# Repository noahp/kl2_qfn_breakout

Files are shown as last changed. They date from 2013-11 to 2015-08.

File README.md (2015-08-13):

kl2_qfn_breakout
================

Breakout for Freescale Kinetis MKL24Z64VFM4 in 32-QFN package.

http://www.freescale.com/webapp/sps/site/prod_summary.jsp?code=KL2  
front  
back

kl24 part
=====
mouser
-----
http://www.mouser.com/ProductDetail/Freescale-Semiconductor/MKL24Z64VFM4/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

digkey
-----
http://www.digikey.com/product-search/en?x=-1066&y=-70&lang=en&site=us&KeyWords=MKL24Z64VFM4

manual
-----
http://cache.freescale.com/files/32bit/doc/ref_manual/KL24P80M48SF0RM.pdf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

part spec
-----
http://www.mouser.com/ds/2/161/KL24P80M48SF0-218435.pdf

symbol
-----
http://www.freescale.com/files/capture/pdf/mkl24z32vfm4_qfn32.pdf

package
-----
http://www.freescale.com/webapp/search.partparamdetail.framework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

pads
-----
http://cache.freescale.com/files/shared/doc/package_info/98ASA00473D.pdf

other parts
=====
usb micro b
-----
[ebay micro b w/ mechanical](http://www.ebay.com/itm/50Pcs-Micro-USB-Type-B-Female-Socket-4-Vertical-Legs-fixed-Solder-Connectors-/171315639526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)  
[mouser micro b smt only](http://www.mouser.com/ProductDetail/FCI/10118192-0001LF/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)

10 pin header
-----
http://www.mouser.com/ProductDetail/FCI/20021121-00010T4LF/?qs=sGAEpiMZZMvffgRu4KC1R10eT3mhH9PKH6si4hSOVY4%3d

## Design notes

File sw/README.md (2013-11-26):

How to set up toolchain + debugger
=====
I'm using gcc-arm, codeblocks, and SEGGER J-Link.  
Note that I had good results with a project directory path with no spaces.

Setup
-----
1. download & install gcc-arm tools, I'm using v4.7-2013-q3-update.
2. download & install codeblocks, if on windows no need for mingw. I'm using v12.11 of codeblocks.
3. setup codeblocks debug settings under Settings->Debugger...
debug common settings  
CRITICAL! must check "Full (Debug) log for debug to work on my setup.  
add config  
Executable path is the path to arm-none-eabi-gdb  
config gcc arm debug
4. setup codeblocks with gcc-arm compiler & linker, Settings->Compiler...
compiler settings
compiler search dirs
under Advanced options...->Others
compiler advanced options
5. install SEGGER J-Link software. it's a good idea to check if you can connect to the target using the J-Link Commander tool, to verify your connections/drivers are working.

Use
-----
1. open the codeblocks project file.
2. start J-Link gdb server. I run the JLinkGDBServerCL with the following arguments:  
$JLinkGDBServer -select USB -device MKL25Z32xxx4 -if SWD -speed auto
3. start debugging. you should be able to set breakpoints etc. from within the IDE.

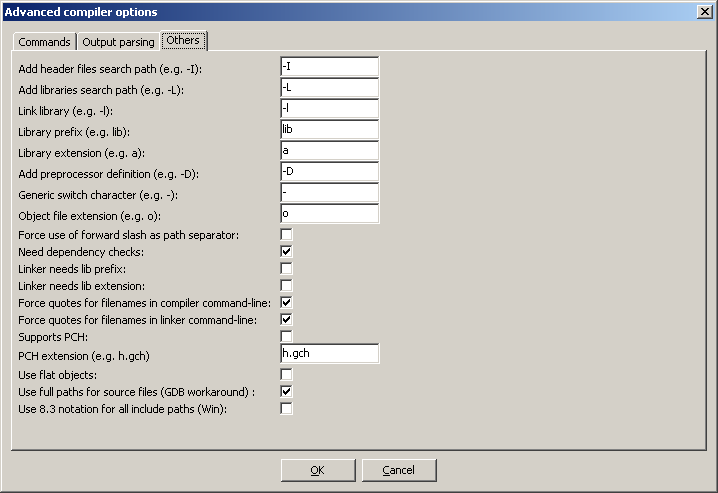
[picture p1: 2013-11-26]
sw/docs/compiler_adv.png

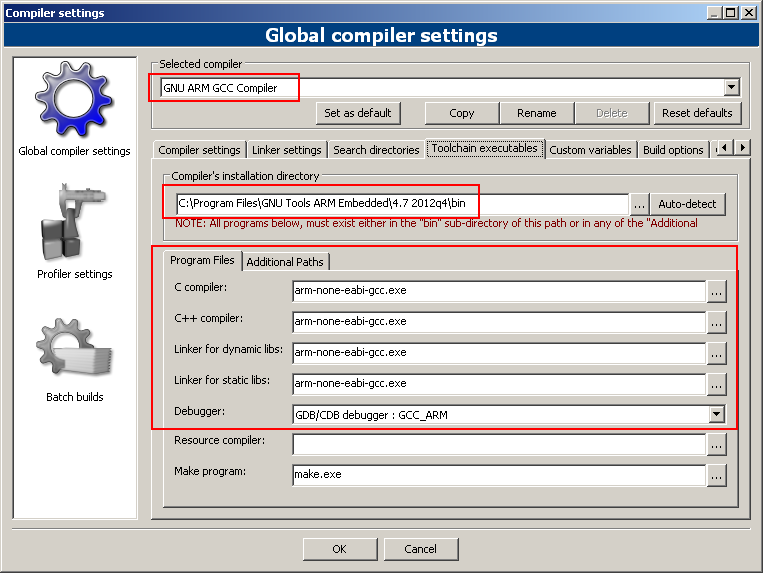
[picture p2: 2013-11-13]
sw/docs/compiler_cfg.png

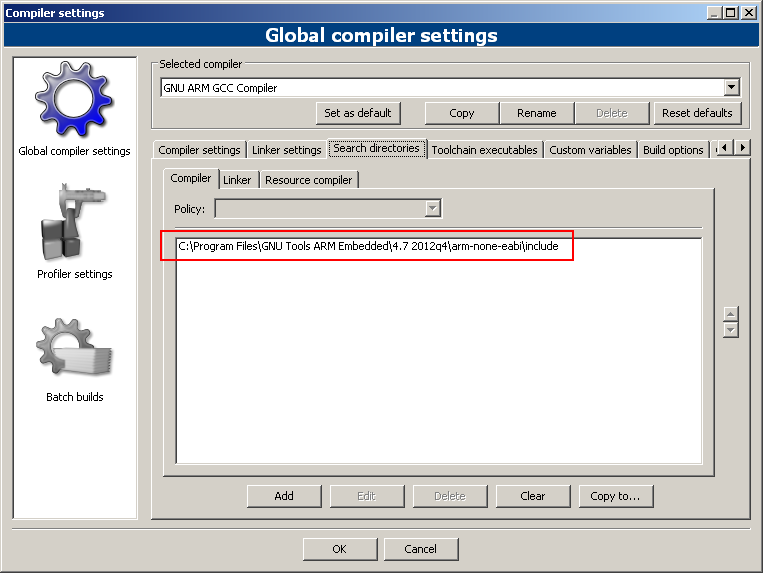
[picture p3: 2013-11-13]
sw/docs/compiler_cfg_search.png

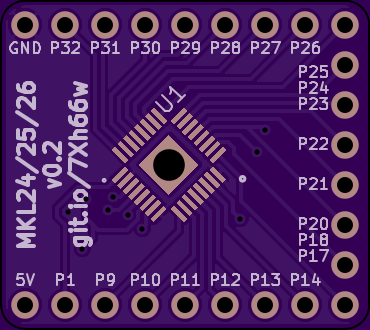
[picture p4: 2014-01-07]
hw/front_render.png

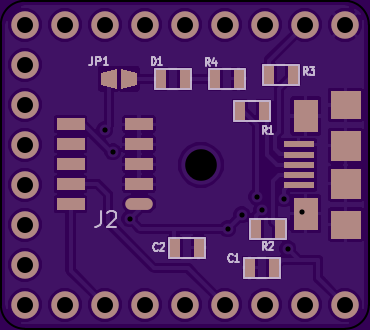
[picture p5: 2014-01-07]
hw/back_render.png

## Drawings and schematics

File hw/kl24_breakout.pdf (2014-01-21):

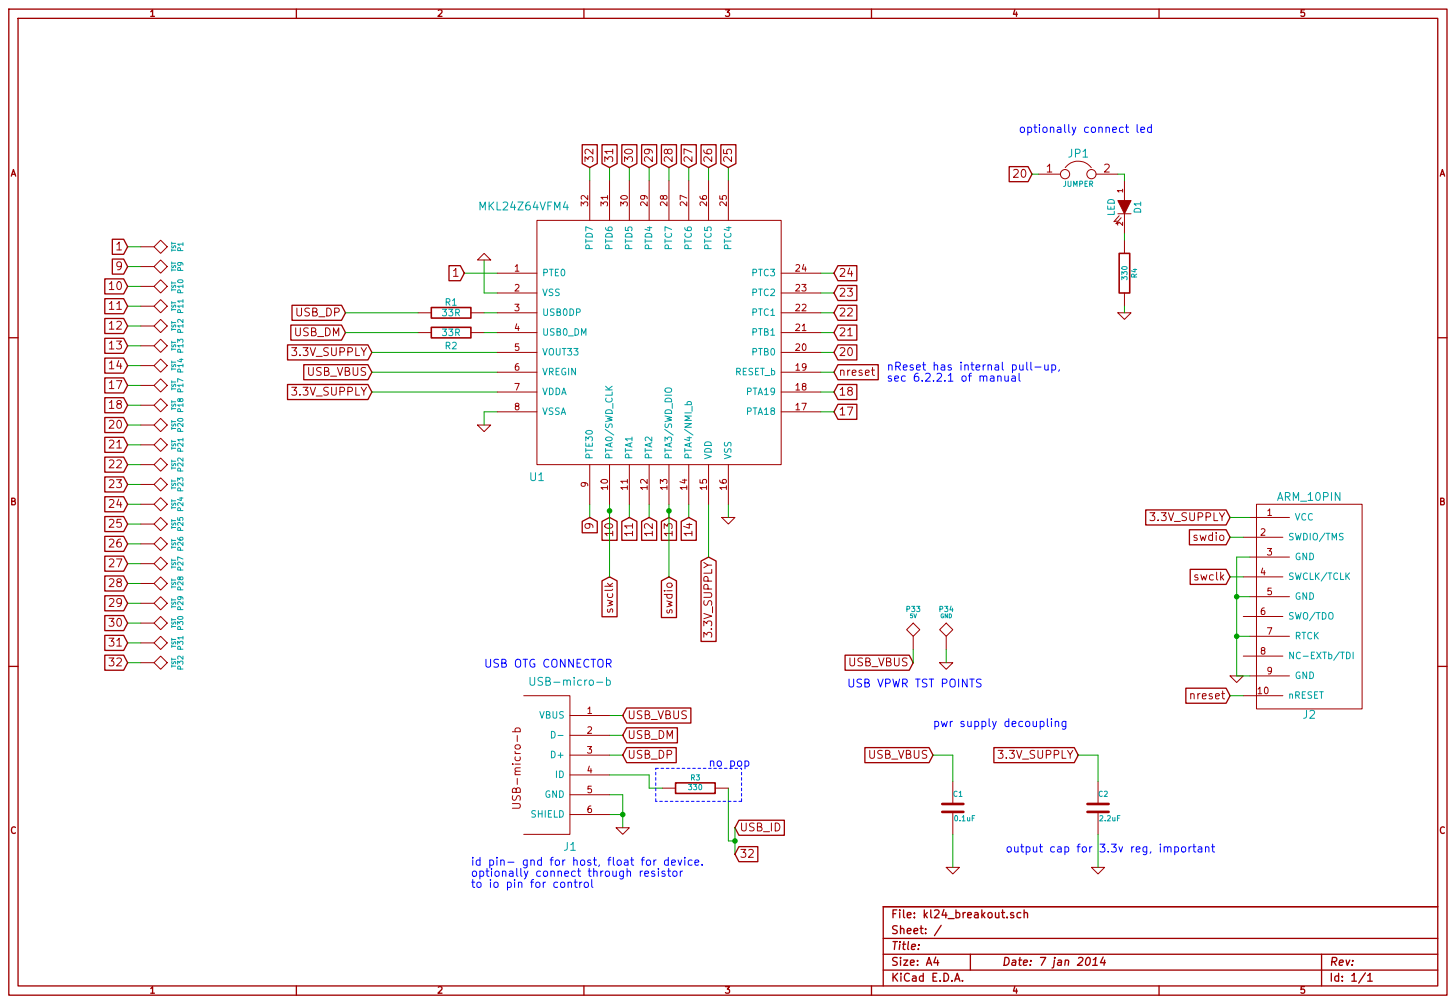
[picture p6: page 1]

optionally connect led
nReset has internal pull-up, sec 6.2.2.1 of manual pwr supply decoupling

USB VPWR TST POINTS

USB_ID
output cap for 3.3v reg, important 32

id pin- gnd for host, float for device.
optionally connect through resistor

Id: 1/1 Title: File: kl24_breakout.sch
Sheet: /

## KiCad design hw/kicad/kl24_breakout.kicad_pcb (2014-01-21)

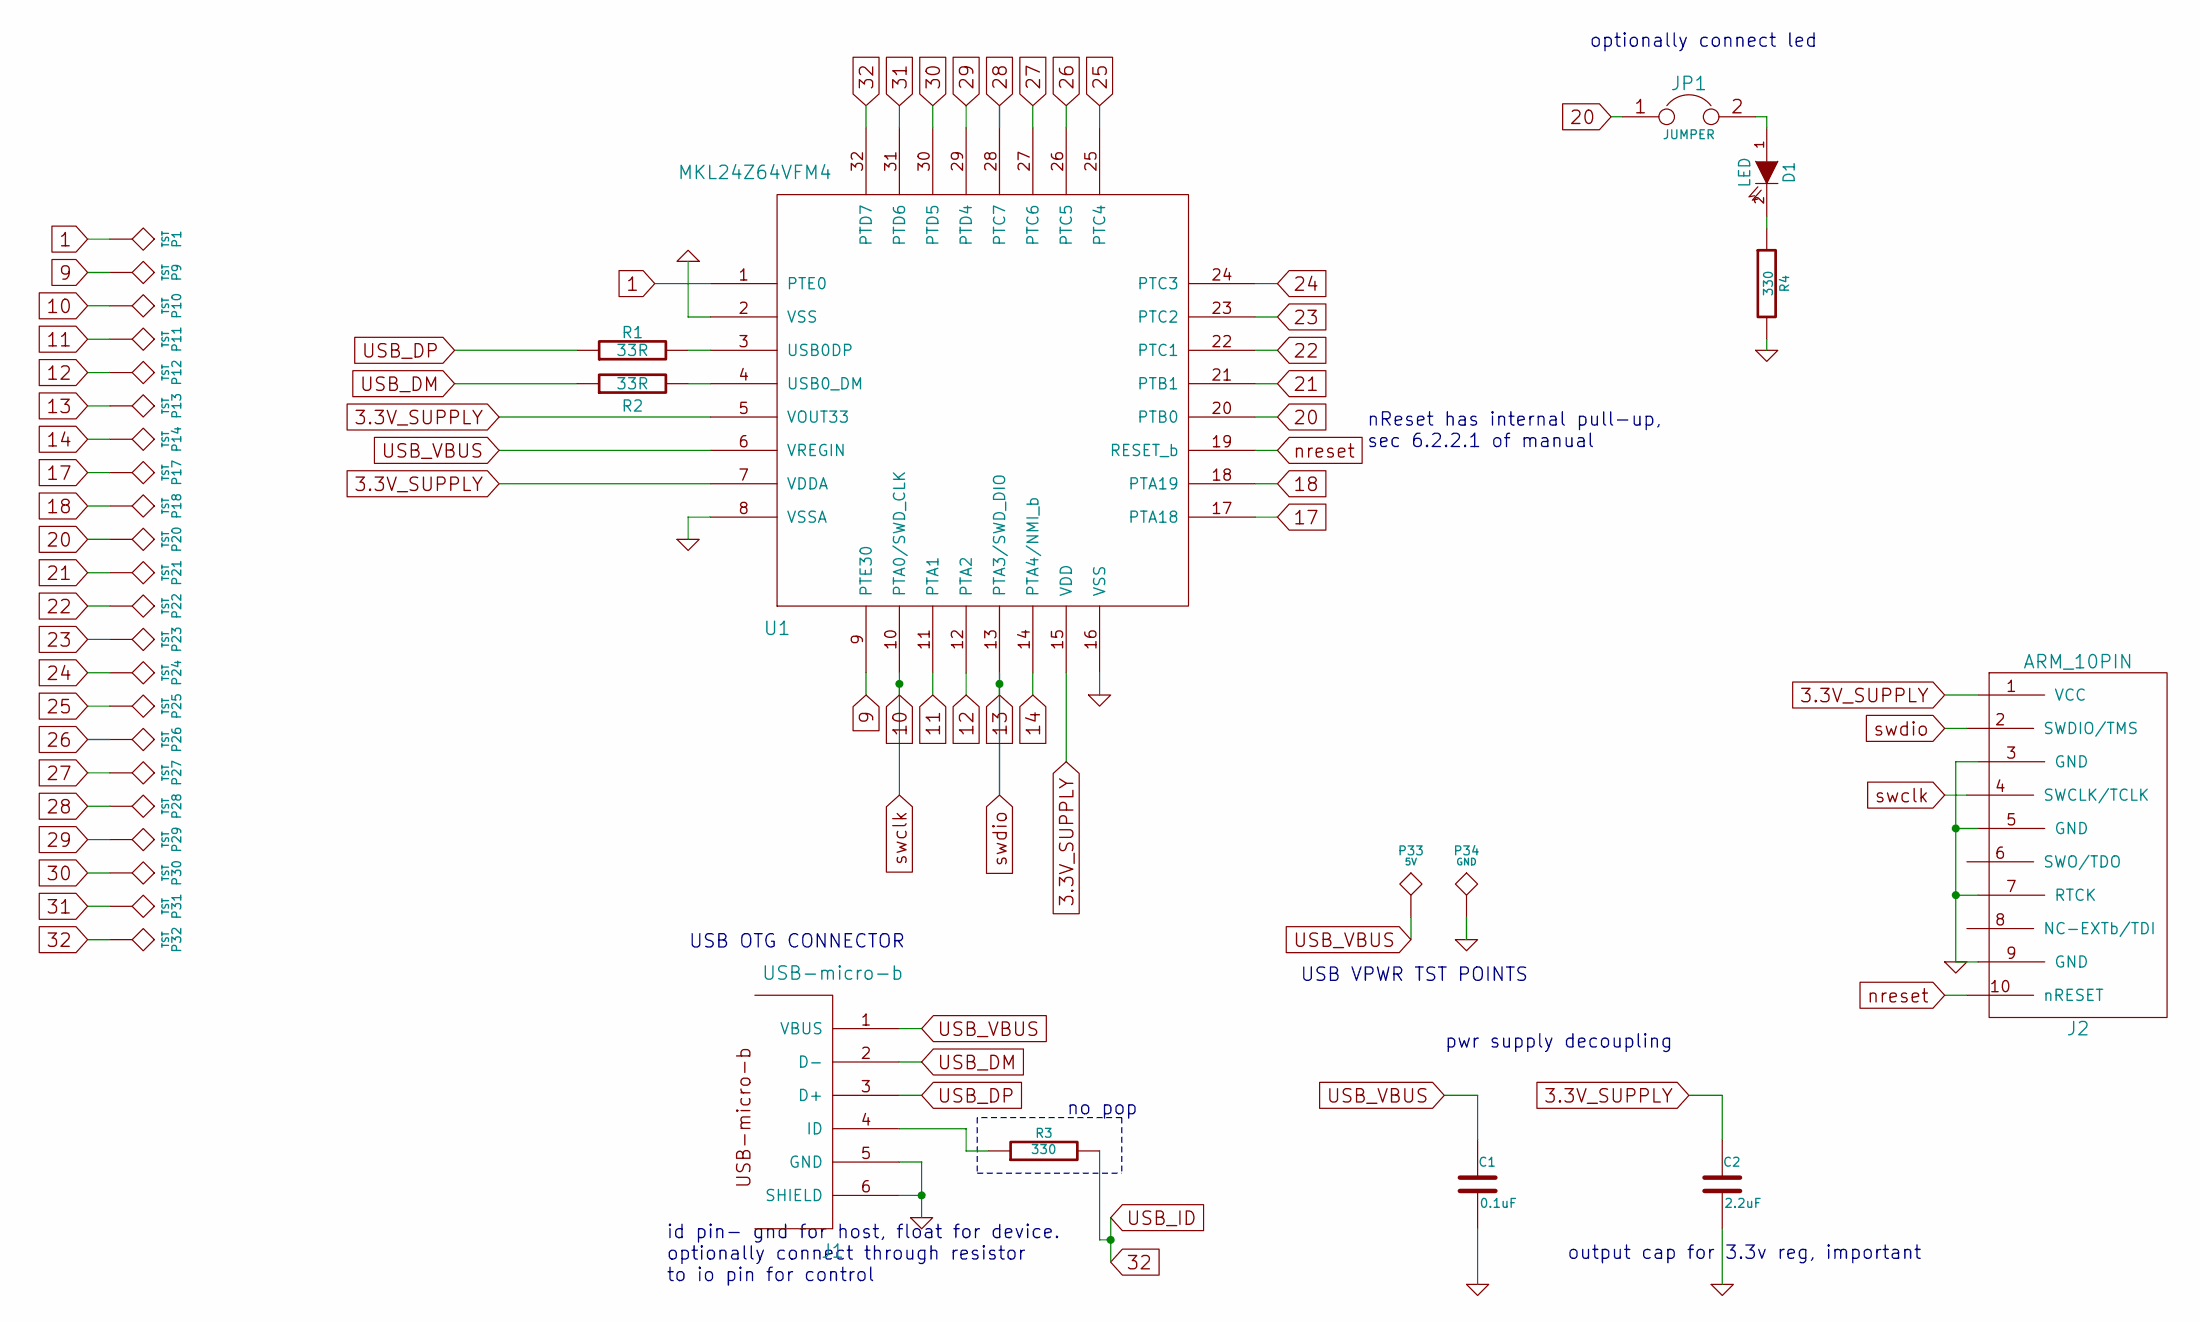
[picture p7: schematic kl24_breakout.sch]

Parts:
C1: 0.1uF
C2: 2.2uF
D1: LED
J1: USB-micro-b
J2: ARM_10PIN
JP1: JUMPER
P1, P9, P10, P11, P12, P13, P14, P17, P18, P20, P21, P22, P23, P24, P25, P26, P27, P28, P29, P30, P31, P32: TST
P33: 5V
P34: GND
R1, R2: 33R
R3, R4: 330
U1: MKL24Z64VFM4

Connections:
1: P1.1, U1.1 (PTE0)
3.3V_SUPPLY: C2.1, J2.1 (VCC), U1.5 (VOUT33), U1.7 (VDDA), U1.15 (VDD)
9: P9.1, U1.9 (PTE30)
10: J2.4 (SWCLK/TCLK), P10.1, U1.10 (PTA0/SWD_CLK)
11: P11.1, U1.11 (PTA1)
12: P12.1, U1.12 (PTA2)
13: J2.2 (SWDIO/TMS), P13.1, U1.13 (PTA3/SWD_DIO)
14: P14.1, U1.14 (PTA4/NMI_b)
17: P17.1, U1.17 (PTA18)
18: P18.1, U1.18 (PTA19)
20: JP1.1, P20.1, U1.20 (PTB0)
21: P21.1, U1.21 (PTB1)
22: P22.1, U1.22 (PTC1)
23: P23.1, U1.23 (PTC2)
24: P24.1, U1.24 (PTC3)
25: P25.1, U1.25 (PTC4)
26: P26.1, U1.26 (PTC5)
27: P27.1, U1.27 (PTC6)
28: P28.1, U1.28 (PTC7)
29: P29.1, U1.29 (PTD4)
30: P30.1, U1.30 (PTD5)
31: P31.1, U1.31 (PTD6)
32: P32.1, R3.2, U1.32 (PTD7)
GND: C1.2, C2.2, J1.5 (GND), J1.6 (SHIELD), J2.3 (GND), J2.5 (GND), J2.7 (RTCK), J2.9 (GND), P34.1, R4.2, U1.2 (VSS), U1.8 (VSSA), U1.16 (VSS)
unnamed: R1.2, U1.3 (USB0DP)
unnamed: R2.2, U1.4 (USB0_DM)
unnamed: J1.4 (ID), R3.1
unnamed: D1.1 (A), JP1.2
unnamed: D1.2 (K), R4.1
USB_DM: J1.2 (D-), R2.1
USB_DP: J1.3 (D+), R1.1
USB_VBUS: C1.1, J1.1 (VBUS), P33.1, U1.6 (VREGIN)
nreset: J2.10 (nRESET), U1.19 (RESET_b)

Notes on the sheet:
USB OTG CONNECTOR
id pin- gnd for host, float for device. optionally connect through resistor to io pin for control
USB VPWR TST POINTS
no pop
nReset has internal pull-up, sec 6.2.2.1 of manual
pwr supply decoupling
optionally connect led
output cap for 3.3v reg, important

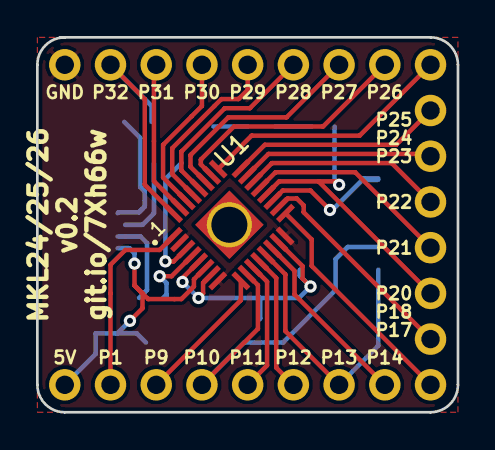
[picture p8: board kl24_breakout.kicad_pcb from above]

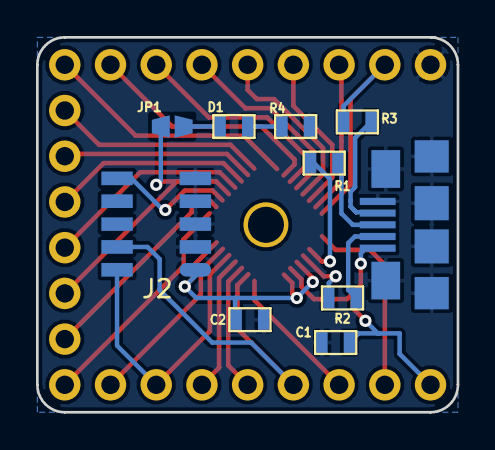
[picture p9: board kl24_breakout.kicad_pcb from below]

Board: 2 copper layers, 23.4 x 20.8 mm, 35 parts (10 on the bottom side), 33 nets.

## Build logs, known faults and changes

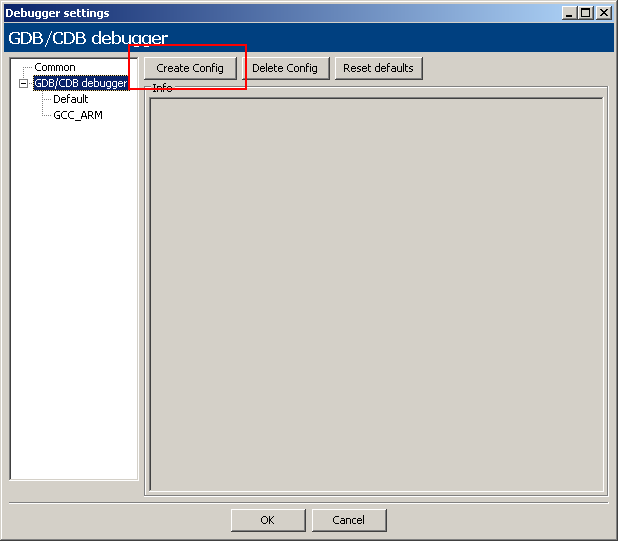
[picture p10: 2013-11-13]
sw/docs/gdb_debug.png

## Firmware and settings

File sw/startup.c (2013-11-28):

#include "MKL25Z4.h"

//*****************************************************************************
//
// Stack Configuration
//
//*****************************************************************************
//
// Stack size (in Words)
//
#define STACK_SIZE       0x00000100
__attribute__ ((section(".co_stack")))
unsigned long pulStack[STACK_SIZE];

//
// Flash configuration fields, be careful modifying these as the chip can be
//  permanently secured! See section 27.3.1 of the user manual,
//  "Flash Configuration Field Description".
//
__attribute__ ((section(".flashconfig")))
const unsigned long flashConfig[] = {
    0xffffffff, 0xffffffff,
    0xffffffff, 0xfffffffe,
};

#define WEAK __attribute__ ((weak))

//*****************************************************************************
//
// Declaration of the default fault handlers
//
//*****************************************************************************
void WEAK  ResetHandler(void);
void WEAK  NMIIntHandler(void);
void WEAK  HardFaultIntHandler(void);
void WEAK  MemManageIntHandler(void);
void WEAK  BusFaultIntHandler(void);
void WEAK  UsageFaultIntHandler(void);
void WEAK  SVCIntHandler(void);
void WEAK  DebugMonIntHandler(void);
void WEAK  PendSVIntHandler(void);
void WEAK  SysTickIntHandler(void);

void WEAK  DMA0IntHandler(void);
void WEAK  DMA1IntHandler(void);
void WEAK  DMA2IntHandler(void);
void WEAK  DMA3IntHandler(void);
void WEAK  FTFAIntHandler(void);
void WEAK  LVDIntHandler(void);
void WEAK  LLWUIntHandler(void);
void WEAK  I2C0IntHandler(void);
void WEAK  I2C1IntHandler(void);
void WEAK  SPI0IntHandler(void);
void WEAK  SPI1IntHandler(void);
void WEAK  UART0SEIntHandler(void);
void WEAK  UART1SEIntHandler(void);
void WEAK  UART2SEIntHandler(void);
void WEAK  ADCIntHandler(void);
void WEAK  ACMPIntHandler(void);
void WEAK  FTM0IntHandler(void);
void WEAK  FTM1IntHandler(void);
void WEAK  FTM2IntHandler(void);
void WEAK  RTCAIntHandler(void);
void WEAK  RTCSIntHandler(void);
void WEAK  PITIntHandler(void);
void WEAK  USBOTGIntHandler(void);
void WEAK  DACIntHandler(void);
void WEAK  TSIIntHandler(void);
void WEAK  MCGIntHandler(void);
void WEAK  LPTMRIntHandler(void);
void WEAK  PORTAIntHandler(void);
void WEAK  PORTDIntHandler(void);

// Start address for the initialization values of the .data section.
extern unsigned long _sidata;
// Start address for the .data section
extern unsigned long _sdata;
// End address for the .data section
extern unsigned long _edata;
// Start address for the .bss section
extern unsigned long _sbss;
// End address for the .bss section
extern unsigned long _ebss;
// End address for ram
extern void _eram;

extern int main(void);
void ResetHandler(void);
static void DefaultIntHandler(void);

//
// The minimal vector table for a Cortex M0+.  Note that the proper constructs
// must be placed on this to ensure that it ends up at physical address
// 0x00000000.
//
// page 53
__attribute__ ((section(".isr_vector")))
void (* const g_pfnVectors[])(void) =
{
    (void *)&pulStack[STACK_SIZE],          // The initial stack pointer
    ResetHandler,                           // The reset handler
    NMIIntHandler,                          // The NMI handler
    HardFaultIntHandler,                    // The hard fault handler
    0, 0, 0, 0, 0, 0, 0,                    // Reserved
    SVCIntHandler,                          // SVCall handler
    0, 0,                                   // Reserved
    PendSVIntHandler,                       // The PendSV handler
    SysTickIntHandler,                      // The SysTick handler

    DMA0IntHandler,                         // DMA channel 0 transfer complete
                                            // and error handler
    DMA1IntHandler,                         // DMA channel 1 transfer complete
                                            // and error handler
    DMA2IntHandler,                         // DMA channel 2 transfer complete
                                            // and error handler
    DMA3IntHandler,                         // DMA channel 3 transfer complete
                                            // and error handler
    0,                                      // Reserved
    FTFAIntHandler,                         // Command complete and read collision
    LVDIntHandler,                          // Low-voltage detect, low-voltage warning
    LLWUIntHandler,                         // Low Leakage Wakeup
    I2C0IntHandler,                         // I2C0 handler
    I2C1IntHandler,                         // I2C1 handler
    SPI0IntHandler,                         // SPI0 handler
    SPI1IntHandler,                         // SPI1 handler
    UART0SEIntHandler,                      // UART0SE handler
    UART1SEIntHandler,                      // UART1SE handler
    UART2SEIntHandler,                      // UART2SE handler
    ADCIntHandler,                          // ADC handler
    ACMPIntHandler,                         // ACMP handler
    FTM0IntHandler,                         // FTM0 handler
    FTM1IntHandler,                         // FTM1 handler
    FTM2IntHandler,                         // FTM2 handler
    RTCAIntHandler,                         // RTCA handler
    RTCSIntHandler,                         // RTCS handler
    PITIntHandler,                          // PIT handler
    0,                                      // Reserved
    USBOTGIntHandler,                       // USBOTG handler
    DACIntHandler,                          // DAC handler
    TSIIntHandler,                          // TSI handler
    MCGIntHandler,                          // MCG handler
    LPTMRIntHandler,                        // PIT handler
    0,                                      // Reserved
    PORTAIntHandler,                        // PORTA handler
    PORTDIntHandler,                        // PORTD handler
};

void StartupInitClock(void)
{
    // select Mid range of MCG_C4[DRST_DRS], and select DMX32=1.
    // from datasheet, in FEI MCG mode (which is what is used here),
    // setting C4[DMX32] is not recommended:
    //
    // "If the internal reference is trimmed to a frequency above 32.768 kHz,
    //  the greater FLL multiplication factor could potentially push the
    //  microcontroller system clock out of specification and damage the part."
    //
    // do it anyway to try to get closer to 48MHz. the mchck guys do it!
    // read-modify-write.
    MCG_C4 = (MCG_C4 & (~MCG_C4_DRST_DRS_MASK) & (~MCG_C4_DMX32_MASK)) |
              MCG_C4_DRST_DRS(0x1) | (0x1 << MCG_C4_DMX32_SHIFT);

    // debug, output bus clock on pin 24 (C3)
    // set CLKOUT select for "Bus clock", read-modify-write.
    SIM_SOPT2 = (SIM_SOPT2 & ~(SIM_SOPT2_CLKOUTSEL_MASK)) | SIM_SOPT2_CLKOUTSEL(0x2);
    // Enable PortC clock gate
    SIM_SCGC5 |= SIM_SCGC5_PORTC_MASK;
    // Set pin for CLKOUT
    PORTC_PCR3 = PORT_PCR_MUX(5) | PORT_PCR_DSE_MASK;
}

//*****************************************************************************
//
//! \brief This is the code that gets called when the processor first
//! starts execution following a reset event.
//!
//! \param None.
//!
//! Only the absolutely necessary set is performed, after which the
//! application supplied main() routine is called.
//!
//! \return None.
//
//*****************************************************************************
void Default_ResetHandler(void)
{
    unsigned long *pulSrc, *pulDest;

    // clock initialization first
    StartupInitClock();

    // Initialize data and bss
    // Copy the data segment initializers from flash to SRAM
    pulSrc = &_sidata;

    for(pulDest = &_sdata; pulDest < &_edata; )
    {
        *(pulDest++) = *(pulSrc++);
    }

    // Zero fill the bss segment.
    for(pulDest = &_sbss; pulDest < &_ebss; )
    {
        *(pulDest++) = 0;
    }

    // Call the application's entry point.
    main();

    // shouldn't return
    while(1);
}

//*****************************************************************************
//
// Provide weak aliases for each Exception handler to the DefaultIntHandler.
// As they are weak aliases, any function with the same name will override
// this definition.
//
//*****************************************************************************
#pragma weak ResetHandler = Default_ResetHandler
#pragma weak NMIIntHandler = DefaultIntHandler
#pragma weak HardFaultIntHandler = DefaultIntHandler
#pragma weak MemManageIntHandler = DefaultIntHandler
#pragma weak BusFaultIntHandler = DefaultIntHandler
#pragma weak UsageFaultIntHandler = DefaultIntHandler
#pragma weak SVCIntHandler = DefaultIntHandler
#pragma weak DebugMonIntHandler = DefaultIntHandler
#pragma weak PendSVIntHandler = DefaultIntHandler
#pragma weak SysTickIntHandler = DefaultIntHandler
#pragma weak DMA0IntHandler = Default_ResetHandler
#pragma weak DMA1IntHandler = Default_ResetHandler
#pragma weak DMA2IntHandler = Default_ResetHandler
#pragma weak DMA3IntHandler = Default_ResetHandler
#pragma weak FTFAIntHandler = Default_ResetHandler
#pragma weak LVDIntHandler = Default_ResetHandler
#pragma weak LLWUIntHandler = Default_ResetHandler
#pragma weak I2C0IntHandler = Default_ResetHandler
#pragma weak I2C1IntHandler = Default_ResetHandler
#pragma weak SPI0IntHandler = Default_ResetHandler
#pragma weak SPI1IntHandler = Default_ResetHandler
#pragma weak UART0SEIntHandler = Default_ResetHandler
#pragma weak UART1SEIntHandler = Default_ResetHandler
#pragma weak UART2SEIntHandler = Default_ResetHandler
#pragma weak ADCIntHandler = Default_ResetHandler
#pragma weak ACMPIntHandler = Default_ResetHandler
#pragma weak FTM0IntHandler = Default_ResetHandler
#pragma weak FTM1IntHandler = Default_ResetHandler
#pragma weak FTM2IntHandler = Default_ResetHandler
#pragma weak RTCAIntHandler = Default_ResetHandler
#pragma weak RTCSIntHandler = Default_ResetHandler
#pragma weak PITIntHandler = Default_ResetHandler
#pragma weak USBOTGIntHandler = Default_ResetHandler
#pragma weak DACIntHandler = Default_ResetHandler
#pragma weak TSIIntHandler = Default_ResetHandler
#pragma weak MCGIntHandler = Default_ResetHandler
#pragma weak LPTMRIntHandler = Default_ResetHandler
#pragma weak PORTAIntHandler = Default_ResetHandler
#pragma weak PORTDIntHandler = Default_ResetHandler

//*****************************************************************************
//  Default interrupt handler
//*****************************************************************************
static void DefaultIntHandler(void)
{
    // Go into an infinite loop.
    while(1);
}

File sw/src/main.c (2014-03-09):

#include "MKL25Z4.h"
#include "systick.h"

// some pin abstractions
#define SET_RST()   (GPIOC_PSOR = (1 << 7))
#define CLR_RST()   (GPIOC_PCOR = (1 << 7))
#define SET_RW()    (GPIOD_PSOR = (1 << 4))
#define CLR_RW()    (GPIOD_PCOR = (1 << 4))
#define SET_DC()    (GPIOD_PSOR = (1 << 6))
#define CLR_DC()    (GPIOD_PCOR = (1 << 6))
#define SET_ERD()   (GPIOD_PSOR = (1 << 5))
#define CLR_ERD()   (GPIOD_PCOR = (1 << 5))

// blocking ms delay
void delay_ms(uint32_t ms)
{
    // get curent time
    uint32_t thisTime = systick_getMs();

    // wait until ms time elapses
    while(systick_getMs() - thisTime < ms);
}

void main_init_io(void)
{
    // init ports
    // disable COP
    SIM_COPC = 0;

    // enable clocks for PORTB
    SIM_SCGC5 |= SIM_SCGC5_PORTB_MASK;

    // set B0 to GPIO
    PORTB_PCR0 = PORT_PCR_MUX(1);

    // set output B0 low (LED on initially)
    GPIOB_PCOR = (1 << 0);

    // set B0 DDR to output
    GPIOB_PDDR |= (1 << 0);
}

void main_init_uart(void)
{
    // turn on io clocks
    SIM_SCGC5 |= SIM_SCGC5_PORTD_MASK;
    // set alternate function 3 for uart0
    PORTD_PCR6 = PORT_PCR_MUX(3);   // rx
    PORTD_PCR7 = PORT_PCR_MUX(3);   // tx

    // turn on uart0 clock
    SIM_SOPT2 |= SIM_SOPT2_UART0SRC(1); // select main clock
    SIM_SCGC4 |= SIM_SCGC4_UART0_MASK;

    // disable tx & rx
    UART0_C2 &= ~(UART_C2_TE_MASK | UART_C2_RE_MASK);

    // baud rate high 4 bits
    UART0_BDH = 0;
    // baud rate low 7 bits
    UART0_BDL = 0xFF;

    // enable tx & rx
    UART0_C2 |= UART_C2_TE_MASK | UART_C2_RE_MASK;
}

void main_led(void)
{
    static uint32_t blinkTime = 0;

    // blink every 250ms
    if(systick_getMs() - blinkTime > 250){
        blinkTime = systick_getMs();
        // toggle
        GPIOB_PTOR = (1 << 0);

        // send a character, once tx data empty bit is set
        while((UART0_S1 & UART0_S1_TDRE_MASK) == 0);
        UART0_D = 0xA5;
    }
}

int main(void) {
    // initialize the necessary
    main_init_io();

    main_init_uart();

    while(1){
        // led task
        main_led();
    }

    return 0;
}

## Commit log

2013-02-28 - add usb socket part ref
2013-02-28 - add kicad proj. + mcu symbol
    [kl24_breakout.sch]
2013-03-01 - reference for 3.3/5v reg, add labels for some modules
    [kl24_breakout.sch]
2013-03-05 - add ref for 3.3 lin reg. add usb conn.
    [kl24_breakout.sch]
2013-03-05 - add the rest of the ic's
    [kl24_breakout.sch]
2013-03-09 - add 0.9v lv battery powered supply (probably nopop)
    [kl24_breakout.sch]
2013-03-09 - add lipo charger circuit
    [kl24_breakout.sch]
2013-03-09 - add some usb things and a crystal+load caps
    [kl24_breakout.sch]
2013-03-10 - add global labels to all pins for breaking out to test pads.
    [kl24_breakout.sch]
2013-03-12 - add some labels to submodules in the schematic
    [kl24_breakout.sch]
2013-03-12 - populate 3.3v supply, som rearragning
    [kl24_breakout.sch]
2013-03-20 - fix some erc's - add test points for all micro pins
    [kl24_breakout.sch]
2013-03-20 - populate 5v boost converter
    [kl24_breakout.sch]
2013-03-22 - add spi flash
    [kl24_breakout.sch]
2013-03-22 - create netlist
    [kl24_breakout.sch]
2013-03-23 - add some sample files and the basics of a cbp project (doesn't work though) for the stm32f0.
    [main.c]
2013-03-23 - delete unneeded files. mingw-make can't build this makefile, compilation error at assembling startup.s
2013-03-26 - try to rework usb host pwr supply, needs an extra switch i'm thinking, so i'm bailing
    [kl24_breakout.sch]
2013-03-26 - remove usb host pwr supply, sch done.
    [kl24_breakout.sch]
2013-04-12 - remove submodule lib - add vcc to arm 10 pin connector
    [kl24_breakout.sch]
2013-04-13 - add schottky part ref - populate some parts.
    [kl24_breakout.sch]
2013-04-13 - add usb pwr points
    [kl24_breakout.sch]
2013-04-13 - add blank pcb - make footprints for all but main micro
    [kl24_breakout.kicad_pcb]
2013-04-13 - last foot print
    [kl24_breakout.kicad_pcb]
2013-04-14 - rebuild arm-10-pin modules and lp3985 (3.3v reg)
    [kl24_breakout.kicad_pcb, kl24_breakout.sch]
2013-04-14 - start pcb
    [kl24_breakout.kicad_pcb]
2013-04-15 - switch arm 10pin header for smt version
    [kl24_breakout.kicad_pcb]
2013-05-19 - remove lv pwr supply
    [kl24_breakout.kicad_pcb, kl24_breakout.sch]
2013-05-22 - remove (local?) kicadlib
2013-05-22 - add submodule for kicadlib back
2013-05-22 - change to smt crystal
    [kl24_breakout.kicad_pcb]
2013-05-23 - redo micro ab connector footprint
    [kl24_breakout.kicad_pcb]
2013-05-24 - add indicator led to schematic
    [kl24_breakout.sch]
2013-05-24 - add indicator led + resitor and jumper to pcb
    [kl24_breakout.kicad_pcb]
2013-06-05 - remove lipo charger
    [kl24_breakout.sch]
2013-06-05 - update pcb with new netlist
    [kl24_breakout.kicad_pcb]
2013-10-05 remove spi flash (maybe sdio instead)
    [kl24_breakout.sch]
2013-10-11 remove 10 pin header
    [kl24_breakout.sch]
2013-10-12 fix up a bit
    [kl24_breakout.kicad_pcb, kl24_breakout.sch]
2013-10-12 fix some pcb labels
    [kl24_breakout.kicad_pcb]
2013-10-12 more pcb
    [kl24_breakout.kicad_pcb]
2013-10-13 all footprints placed, start wiring
    [kl24_breakout.kicad_pcb, kl24_breakout.sch]
2013-10-13 most connections
    [kl24_breakout.kicad_pcb]
2013-10-13 - add schematic pdf
2013-10-14 tweak pcb
    [kl24_breakout.kicad_pcb]
2013-10-14 remove regulator in favor of on-chip 3.3v regulator
    [kl24_breakout.sch]
2013-10-14 finish pcb, add label text
    [kl24_breakout.kicad_pcb]
2013-10-14 gerber output
    [kl24_breakout-B_Cu.gbl, kl24_breakout-B_Mask.gbs, kl24_breakout-B_SilkS.gbo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]
2013-10-14 move label text to the left a bit
    [kl24_breakout.kicad_pcb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]
2013-10-14 update schematic out
2013-10-15 add some decoupling caps to +5 and +3.3 and nreset update to v0.2 replot
    [kl24_breakout-B_Cu.gbl, kl24_breakout-B_Mask.gbs, kl24_breakout-B_SilkS.gbo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]
2013-10-25 - add 10k pullup on nreset
    [kl24_breakout.kicad_pcb, kl24_breakout.sch]
2013-10-25 - add gerbers - update pcb
    [kl24_breakout-B_Cu.gbl, kl24_breakout-B_Mask.gbs, kl24_breakout-B_SilkS.gbo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]
2013-11-20 - switch to DMX32 = 1 in MCG C4 register, this gets it pretty close to 48MHz off internal RC vs. more like 42MHz without it.
2013-11-28 - add interrupts, start breaking them out
2013-11-28 - systick ms timer working
2013-11-29 - spi working ok
2013-12-09 - add sample screen from ada fruit example - correct a few mistakes, add some pin def's - major error, spi polarity should be CPOL=1 >_< , display working now
    [main.c]
2013-12-10 -add fonts, start string print function
2013-12-11 - remove spi/oled stuff
2013-12-30 - remove power pin breakout. add arm 10 pin header.
    [kl24_breakout.kicad_pcb, kl24_breakout.sch]
2014-01-06 - remove crystal
    [kl24_breakout.kicad_pcb, kl24_breakout.sch]
2014-01-06 - edge
    [kl24_breakout.kicad_pcb]
2014-01-06 - layout
    [kl24_breakout.kicad_pcb]
2014-01-06 - save
    [kl24_breakout.kicad_pcb]
2014-01-07 - change to usb-micro-b only
    [kl24_breakout.kicad_pcb, kl24_breakout.sch]
2014-01-07 - layout done for v0.2I think
    [kl24_breakout-B_Cu.gbl, kl24_breakout-B_Mask.gbs, kl24_breakout-B_SilkS.gbo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]
2014-01-21 - fix some minor goofs in the pcb (extra via, extra pin 1 marker for U1)
    [kl24_breakout-B_Cu.gbl, kl24_breakout-B_Mask.gbs, kl24_breakout-B_SilkS.gbo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]
2014-03-08 - try to get the uart0 setup.
